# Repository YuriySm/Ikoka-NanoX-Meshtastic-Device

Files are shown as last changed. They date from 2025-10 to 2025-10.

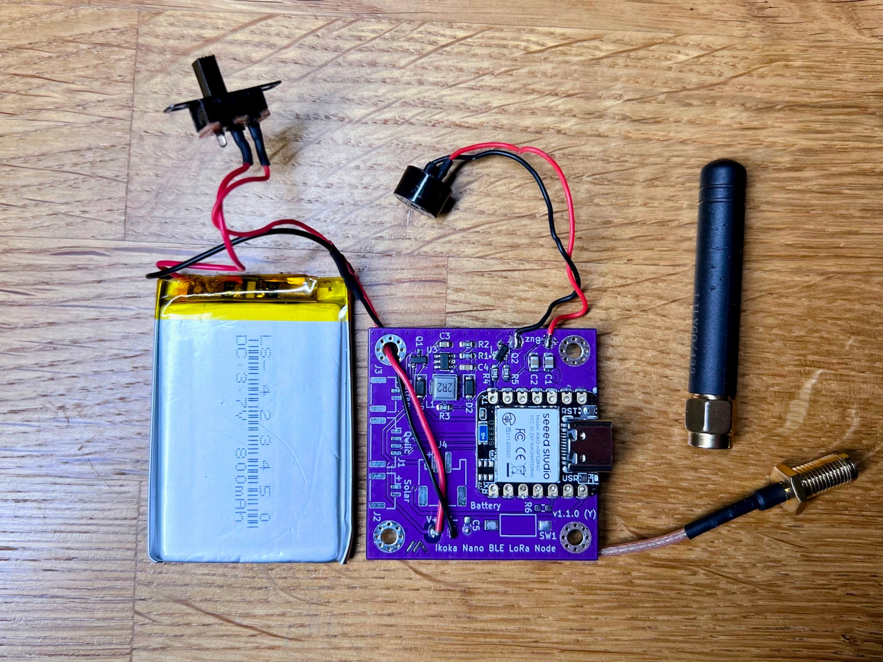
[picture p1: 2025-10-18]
media/1.1.1/Ikoka-NanoX-1.1.1-assembled.png

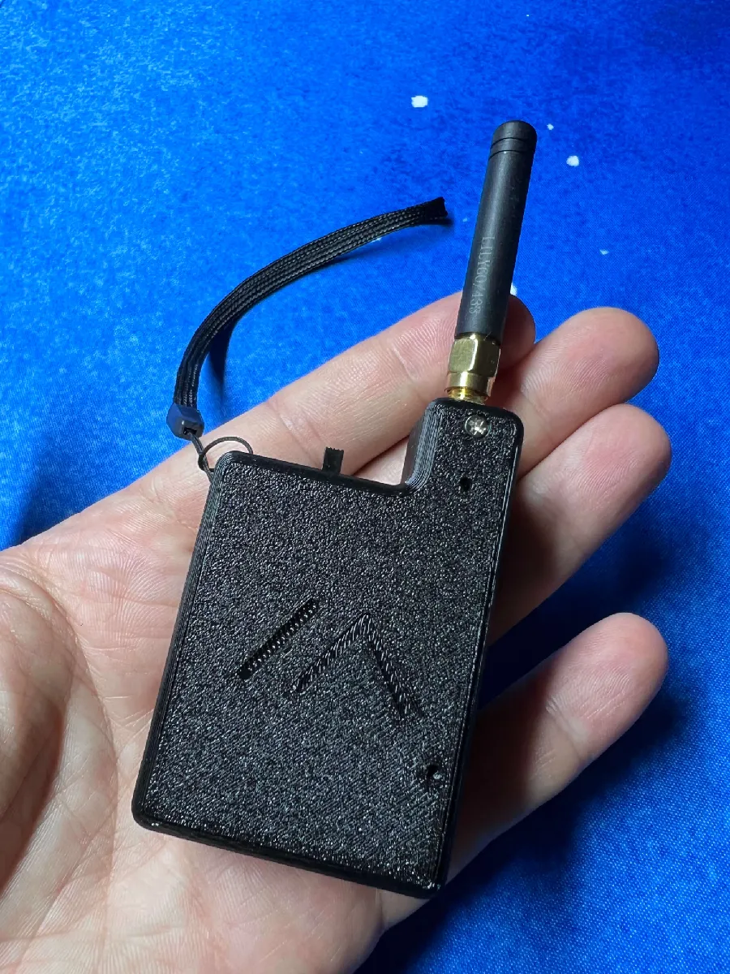
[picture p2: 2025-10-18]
media/1.1.1/Ikoka-NanoX-case.png

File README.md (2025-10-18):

Українська версія 🇺🇦 README доступна в [README_UK-UA.md](README_UK-UA.md).

Ikoka NanoX (eXtended) Meshtastic PCB is a fork of the [Ikoka Nano Meshtastic Device](https://github.com/ndoo/ikoka-nano-meshtastic-device) created by [Andrew Yong](https://ndoo.sg/projects:amateur_radio:meshtastic:diy_devices:ikoka_nano). This is a modified version of the original design released under CERN-OHL-P.

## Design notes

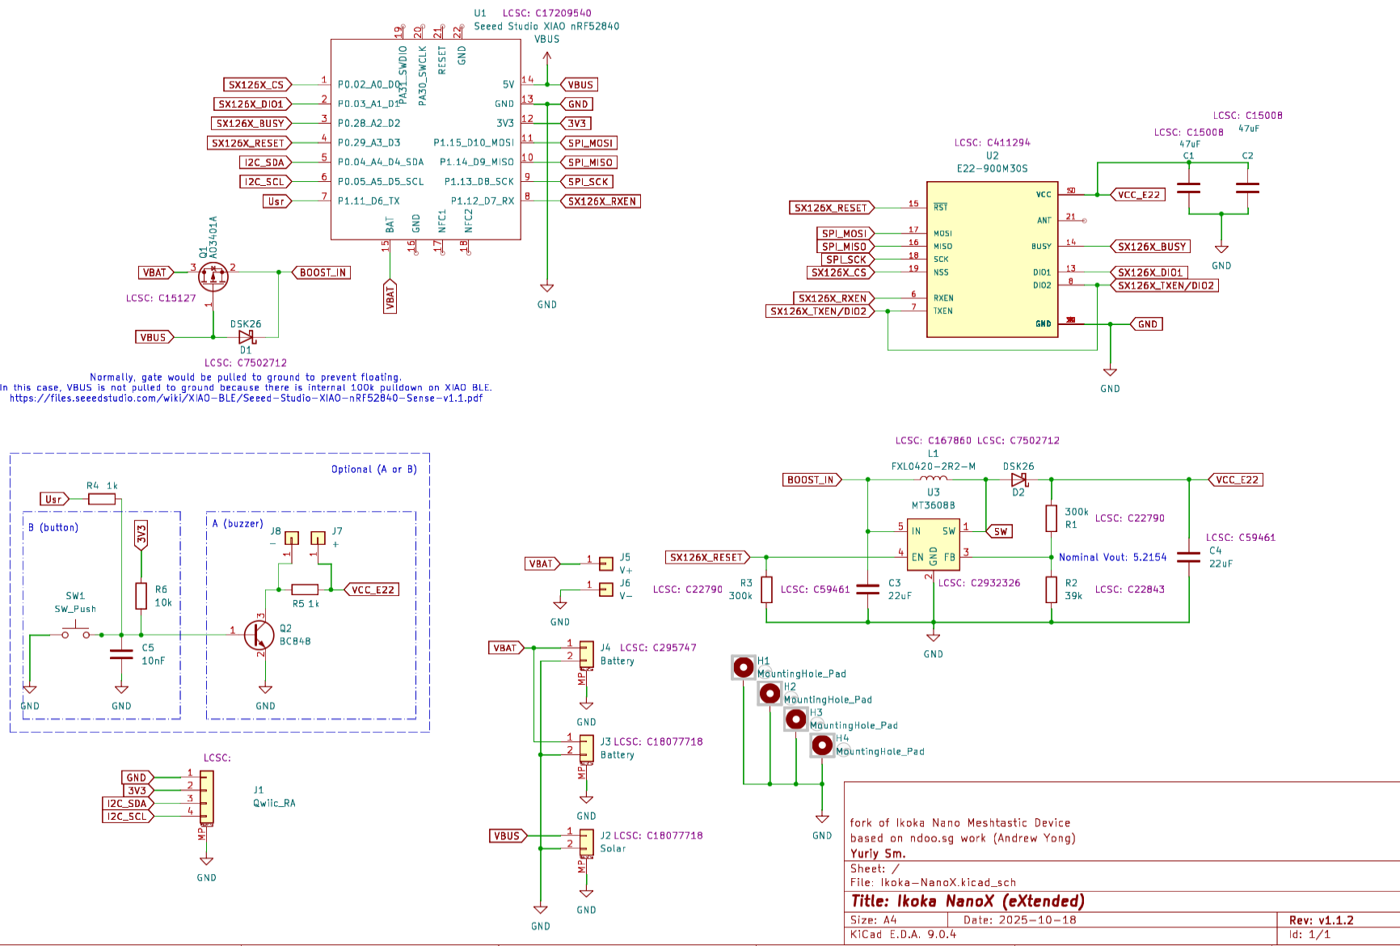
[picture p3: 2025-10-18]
media/1.1.2/IkokaNanoX-1.1.2-schematic.png

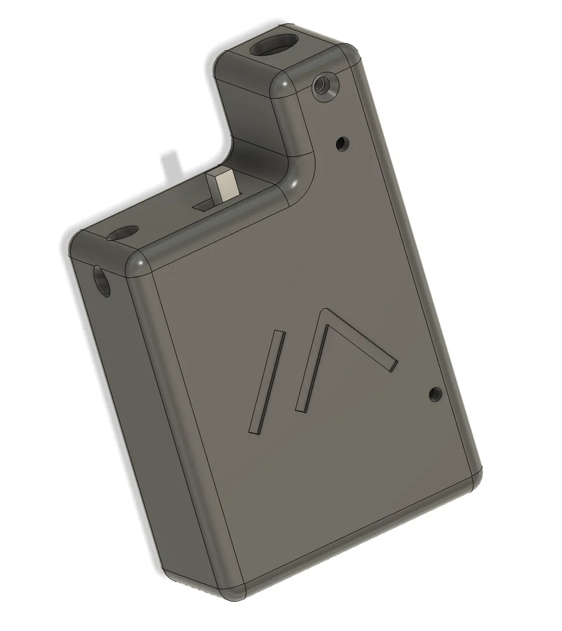
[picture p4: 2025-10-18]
media/1.1.1/Ikoka-NanoX-case-3D.png

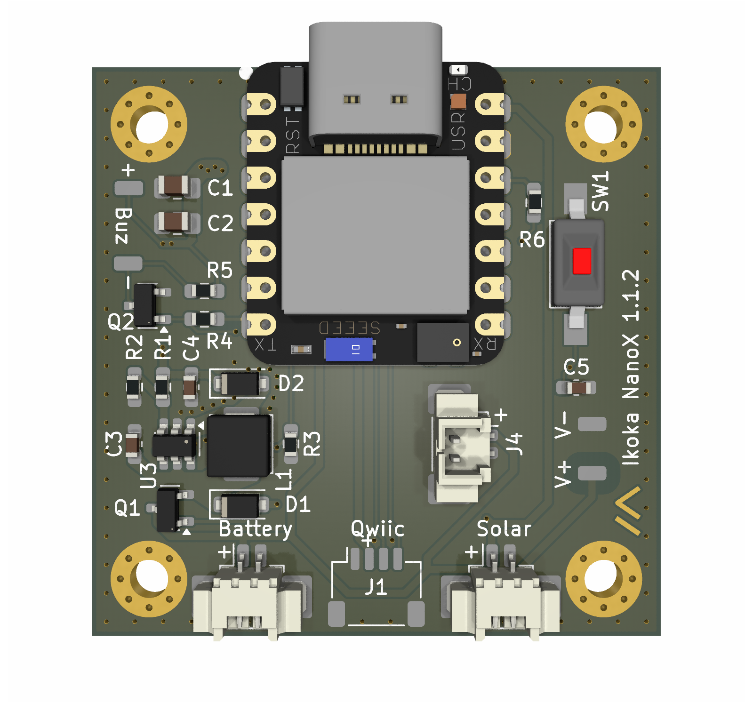
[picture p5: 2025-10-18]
media/1.1.2/Ikoka-NanoX-1.1.2-front.png

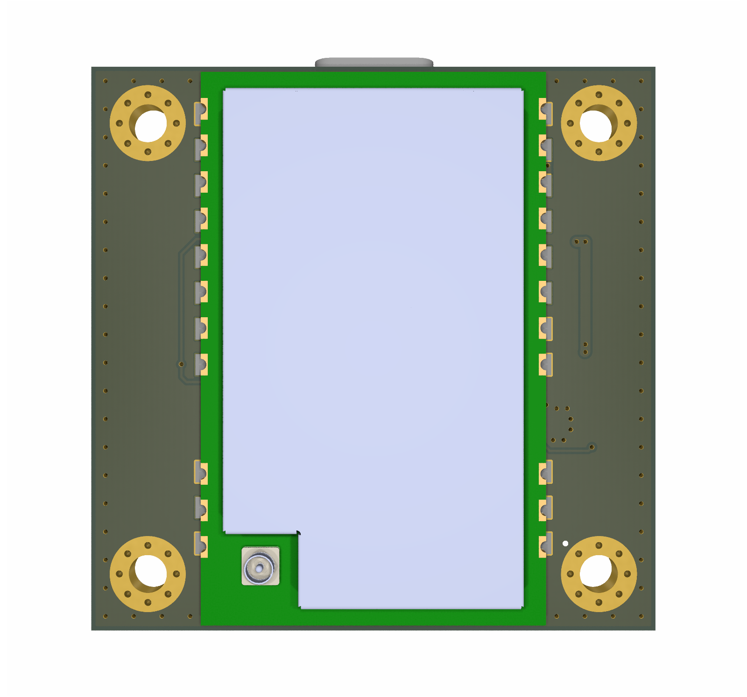
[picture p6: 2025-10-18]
media/1.1.2/Ikoka-NanoX-1.1.2-back.png

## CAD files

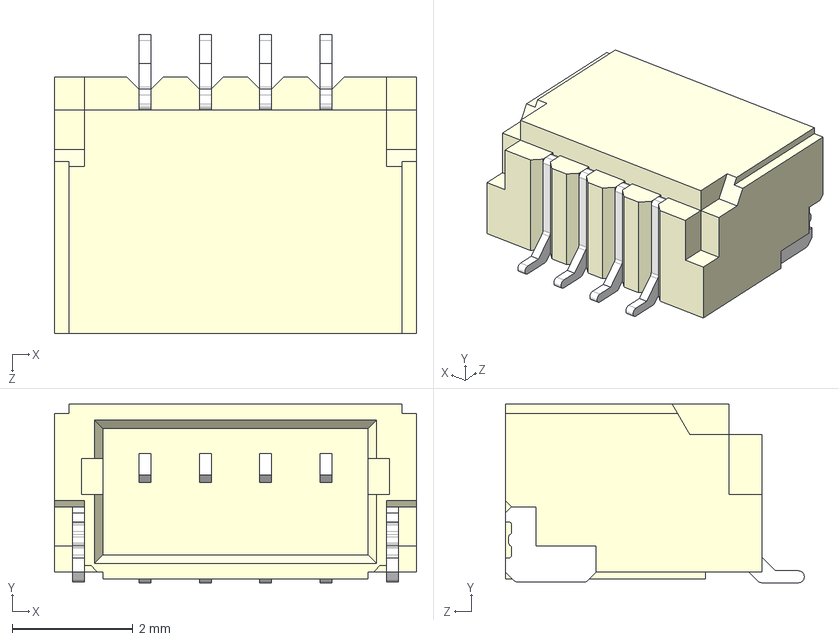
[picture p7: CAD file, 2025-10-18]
Ikoka-NanoX-KiCad/3dmodels/SM04B-SRSS-TB(LF)(SN)--3DModel-STEP-269445.STEP
6.00 x 2.96 x 4.95 mm

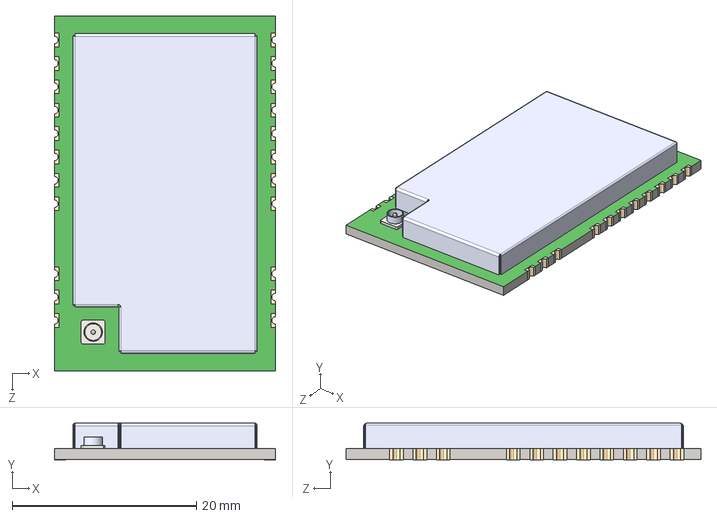
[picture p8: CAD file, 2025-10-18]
Ikoka-NanoX-KiCad/symbols/E22-900M30S/E22-900M30S.step
24.0 x 3.97 x 38.5 mm

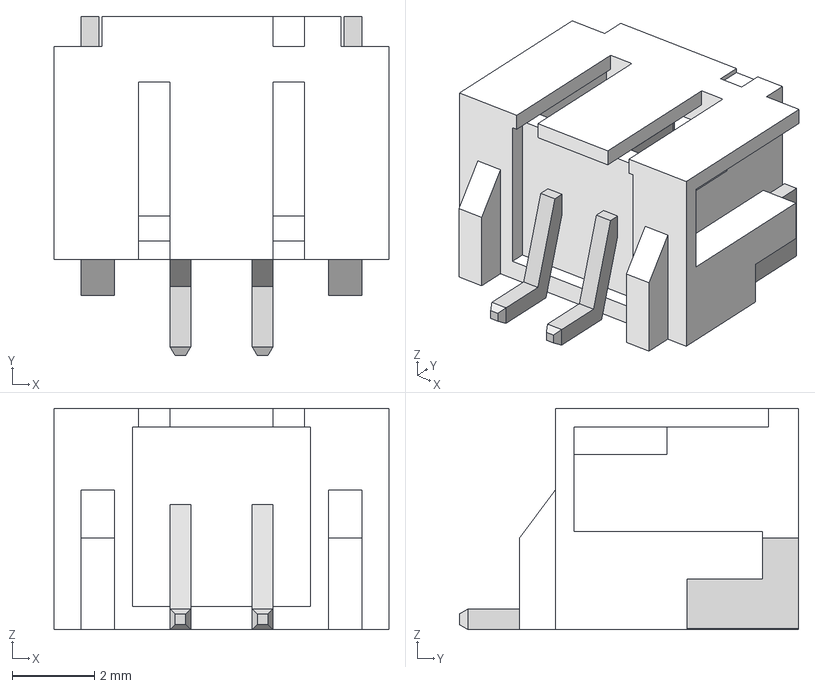
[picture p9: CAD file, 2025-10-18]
Ikoka-NanoX-KiCad/3dmodels/JST - PH - SMD (R) - 2Pin - 2.00mm.stp
8.15 x 8.26 x 5.38 mm

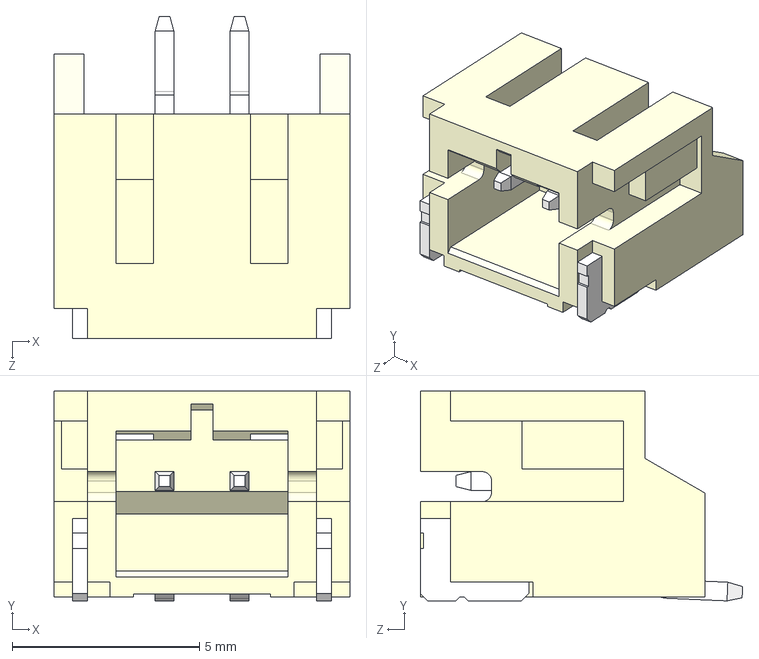
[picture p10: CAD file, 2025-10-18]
Ikoka-NanoX-KiCad/3dmodels/S2B-PH-SM4-TB--3DModel-STEP-269445.STEP
7.90 x 5.60 x 8.60 mm

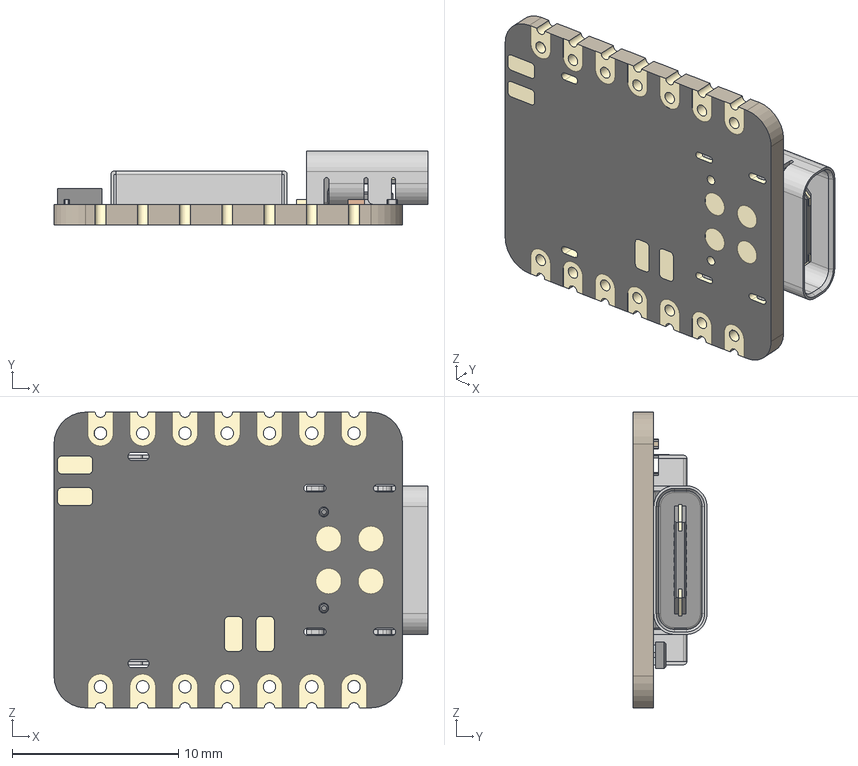
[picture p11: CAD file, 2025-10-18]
Ikoka-NanoX-KiCad/3dmodels/XIAO-nRF52840 v15.step
22.5 x 4.46 x 17.8 mm
BOSS-EXTRUDE14_8_
BOSS-EXTRUDE7_4_
BOSS-EXTRUDE7_3_
BOSS-EXTRUDE14_4_
BOSS-EXTRUDE14_2_
BOSS-EXTRUDE14_11_
BOSS-EXTRUDE7_7_
BOSS-EXTRUDE14_9_
BOSS-EXTRUDE14_3_
BOSS-EXTRUDE14_7_
MIRROR2
BOSS-EXTRUDE14_5_
BOSS-EXTRUDE14_12_
BOSS-EXTRUDE7_8_
BOSS-EXTRUDE7_1_
BOSS-EXTRUDE14_10_
BOSS-EXTRUDE7_9_
BOSS-EXTRUDE14_6_
BOSS-EXTRUDE14_1_
BOSS-EXTRUDE7_6_
BOSS-EXTRUDE7_2_
CUT-EXTRUDE5
BOSS-EXTRUDE7_5_
Shield
Pins
CAP x 2
ANT1
Silkscreen
CAP 3
LED
USR
2 v1

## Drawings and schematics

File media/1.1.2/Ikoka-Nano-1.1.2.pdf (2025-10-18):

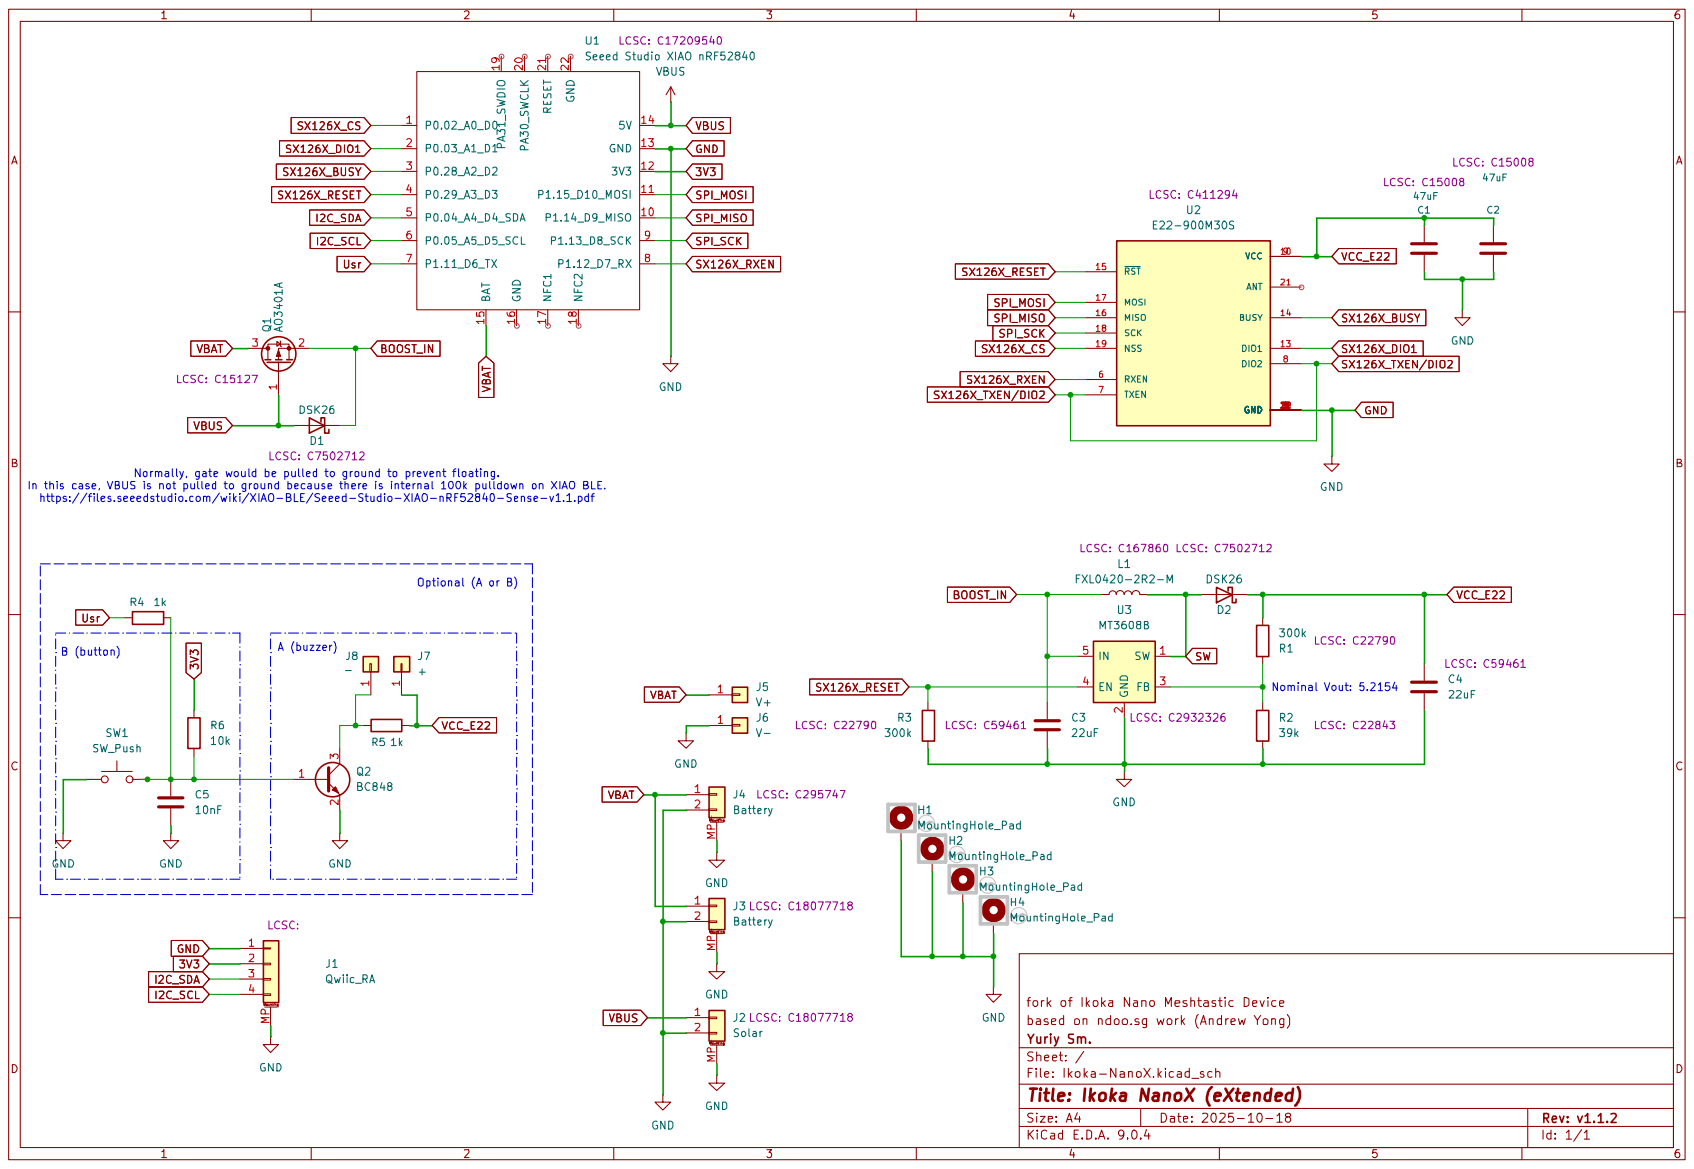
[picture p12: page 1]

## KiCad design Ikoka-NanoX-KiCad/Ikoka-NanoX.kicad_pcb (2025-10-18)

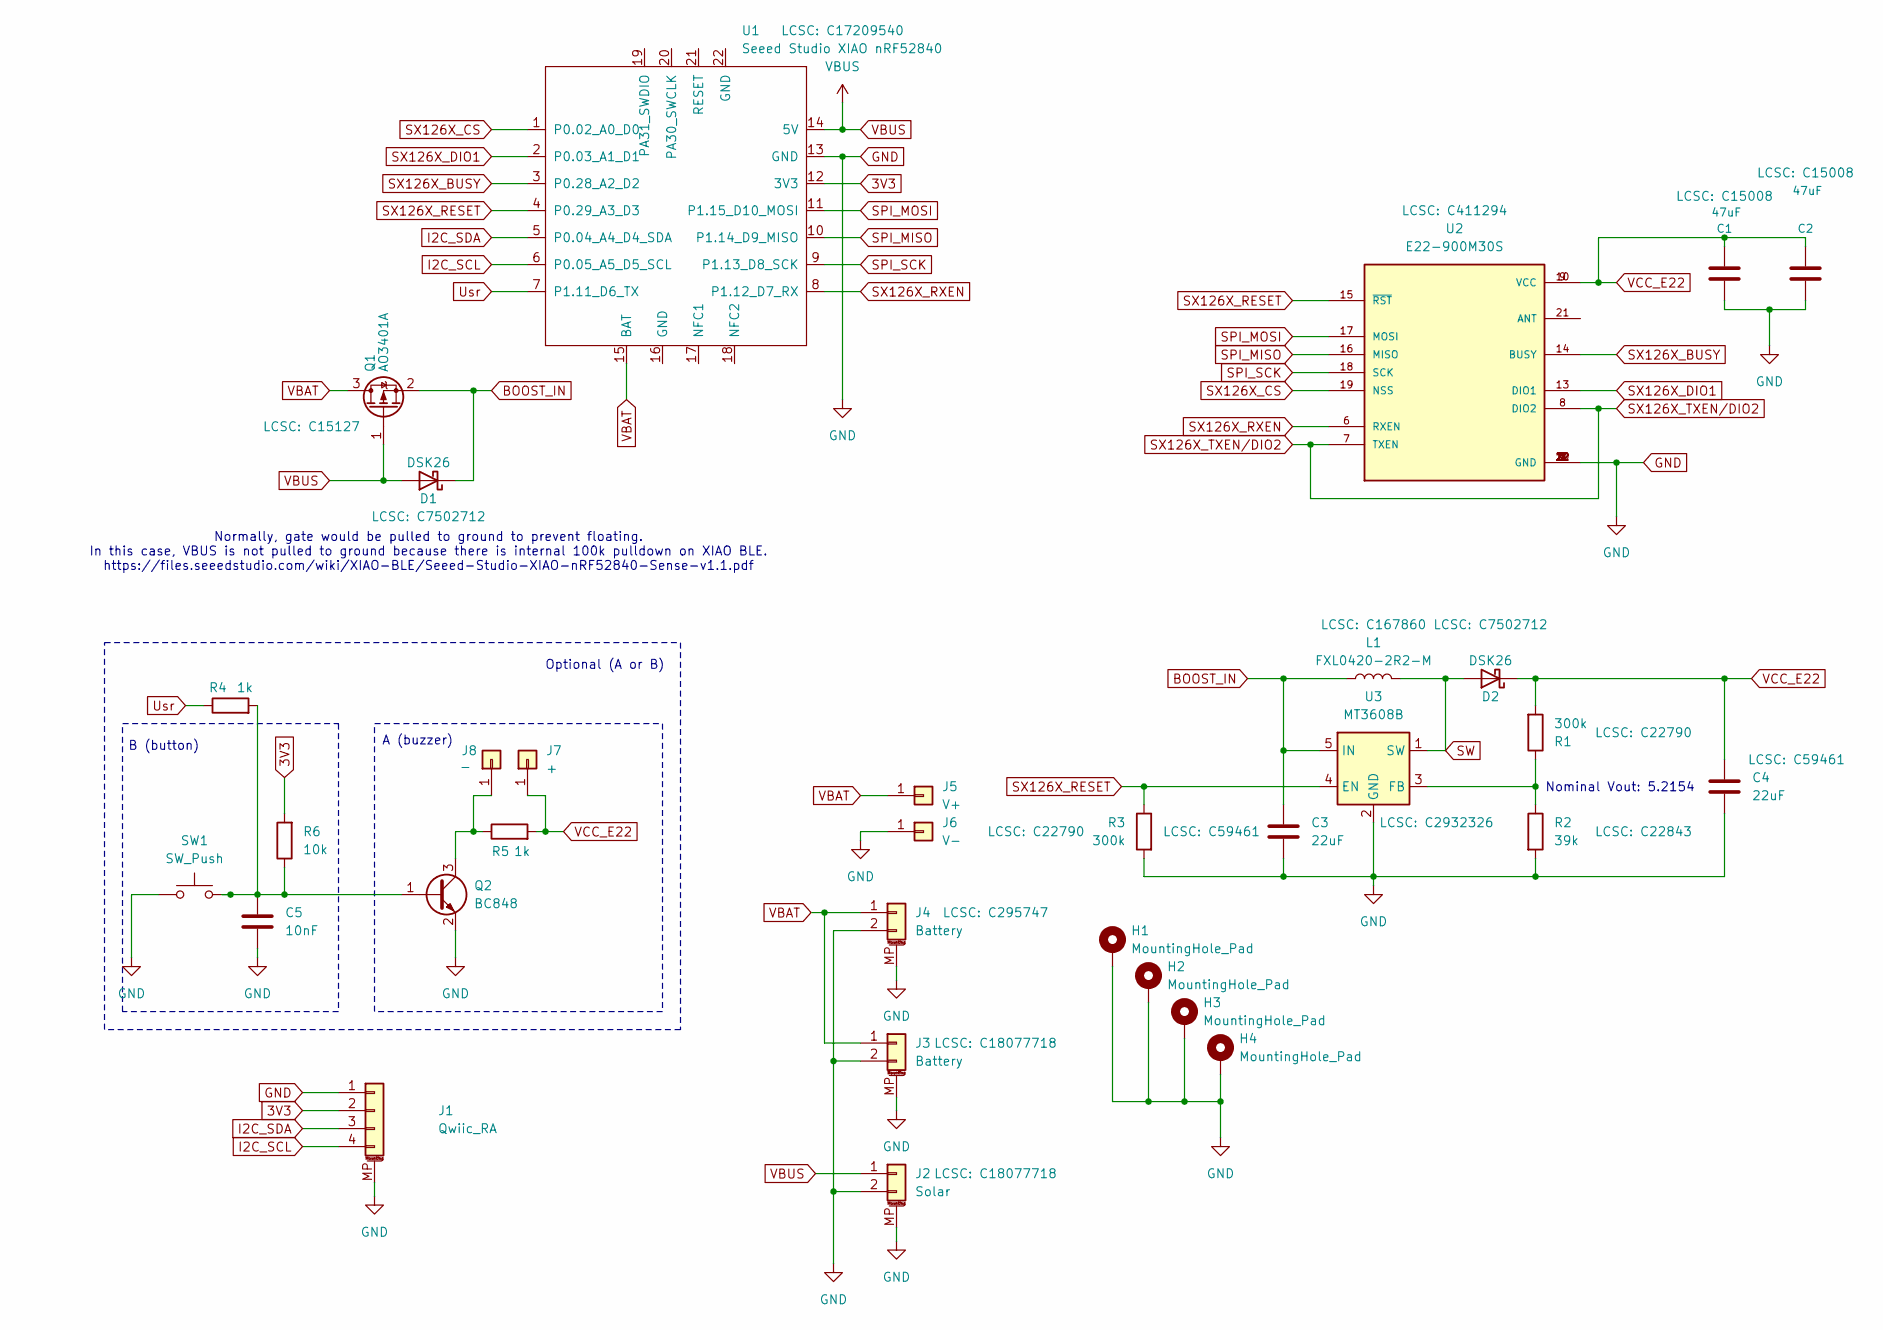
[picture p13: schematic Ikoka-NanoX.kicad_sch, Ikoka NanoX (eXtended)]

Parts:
C1, C2: 47uF; C_0805_2012Metric_Pad1.18x1.45mm_HandSolder; MPN CL31A107MQHNNNE; LCSC C15008
C3, C4: 22uF; C_0603_1608Metric_Pad1.08x0.95mm_HandSolder; MPN CL10A226MQ8NRNC; LCSC C59461
C5: 10nF; C_0603_1608Metric_Pad1.08x0.95mm_HandSolder; MPN CL10A226MQ8NRNC
D1, D2: DSK26; D_SOD-123F; LCSC C7502712
H1, H2, H3, H4: MountingHole_Pad; MountingHole_2.7mm_M2.5_Pad_Via
J1: Qwiic_RA; JST_SH_SM04B-SRSS-TB_1x04-1MP_P1.00mm_Horizontal
J2: Solar; Molex_PicoBlade_53261-0271_1x02-1MP_P1.25mm_Horizontal; LCSC C18077718
J3: Battery; Molex_PicoBlade_53261-0271_1x02-1MP_P1.25mm_Horizontal; LCSC C18077718
J4: Battery; Molex_PicoBlade_53398-0271_1x02-1MP_P1.25mm_Vertical; LCSC C295747
J5: V+; SolderWirePad_1x01_SMD_1x2mm
J6: V-; SolderWirePad_1x01_SMD_1x2mm
J7: +; SolderWirePad_1x01_SMD_1x2mm
J8: -; SolderWirePad_1x01_SMD_1x2mm
L1: FXL0420-2R2-M; L_Changjiang_FXL0420; MPN SMMS0650-220M; LCSC C167860
Q1: AO3401A; SOT-23; LCSC C15127
Q2: BC848; SOT-23
R1, R3: 300k; R_0603_1608Metric_Pad0.98x0.95mm_HandSolder; MPN 0603WAF1502T5E; LCSC C22790
R2: 39k; R_0603_1608Metric_Pad0.98x0.95mm_HandSolder; MPN 0603WAF1871T5E; LCSC C22843
R4, R5: 1k; R_0603_1608Metric_Pad0.98x0.95mm_HandSolder
R6: 10k; R_0603_1608Metric_Pad0.98x0.95mm_HandSolder
SW1: SW_Push; SW_SPST_FSMSM
U1: Seeed Studio XIAO nRF52840; XIAO-nRF52840-SMD_Handsoldering; LCSC C17209540
U2: E22-900M30S; XCVR_E22-900M30S; PARTREV 1.2; LCSC C411294
U3: MT3608B; SOT-23-6; LCSC C2932326

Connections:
3V3: J1.2, R6.2, U1.12 (3V3)
BOOST_IN: C3.1, D1.1 (K), L1.1, Q1.2 (S), U3.5 (IN)
GND: C1.1, C2.1, C3.2, C4.2, C5.2, H1.1, H2.1, H3.1, H4.1, J1.1, J1.MP (MountPin), J2.2, J2.MP (MountPin), J3.2, J3.MP (MountPin), J4.2, J4.MP (MountPin), J6.1, Q2.2 (E), R2.2, R3.2, SW1.1, U1.13 (GND), U2.1 (GND), U2.2 (GND), U2.3 (GND), U2.4 (GND), U2.5 (GND), U2.11 (GND), U2.12 (GND), U2.20 (GND), U2.22 (GND), U3.2 (GND)
I2C_SCL: J1.4, U1.6 (P0.05_A5_D5_SCL)
I2C_SDA: J1.3, U1.5 (P0.04_A4_D4_SDA)
unnamed: J8.1, Q2.3 (C), R5.1
unnamed: C5.1, Q2.1 (B), R4.2, R6.1, SW1.2
unnamed: R1.1, R2.1, U3.3 (FB)
SPI_MISO: U1.10 (P1.14_D9_MISO), U2.16 (MISO)
SPI_MOSI: U1.11 (P1.15_D10_MOSI), U2.17 (MOSI)
SPI_SCK: U1.9 (P1.13_D8_SCK), U2.18 (SCK)
SW: D2.2 (A), L1.2, U3.1 (SW)
SX126X_BUSY: U1.3 (P0.28_A2_D2), U2.14 (BUSY)
SX126X_CS: U1.1 (P0.02_A0_D0), U2.19 (NSS)
SX126X_DIO1: U1.2 (P0.03_A1_D1), U2.13 (DIO1)
SX126X_RESET: R3.1, U1.4 (P0.29_A3_D3), U2.15 (~RST), U3.4 (EN)
SX126X_RXEN: U1.8 (P1.12_D7_RX), U2.6 (RXEN)
SX126X_TXEN/DIO2: U2.7 (TXEN), U2.8 (DIO2)
Usr: R4.1, U1.7 (P1.11_D6_TX)
VBAT: J3.1, J4.1, J5.1, Q1.3 (D), U1.15 (BAT)
VBUS: D1.2 (A), J2.1, Q1.1 (G), U1.14 (5V)
VCC_E22: C1.2, C2.2, C4.1, D2.1 (K), J7.1, R1.2, R5.2, U2.9 (VCC), U2.10 (VCC)

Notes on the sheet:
A (buzzer)
Nominal Vout: 5.2154
B (button)
Normally, gate would be pulled to ground to prevent floating. In this case, VBUS is not pulled to ground because there is internal 100k pulldown on XIAO BLE. https://files.seeedstudio.com/wiki/XIAO-BLE/Seeed-Studio-XIAO-nRF52840-Sense-v1.1.pdf
Optional (A or B)

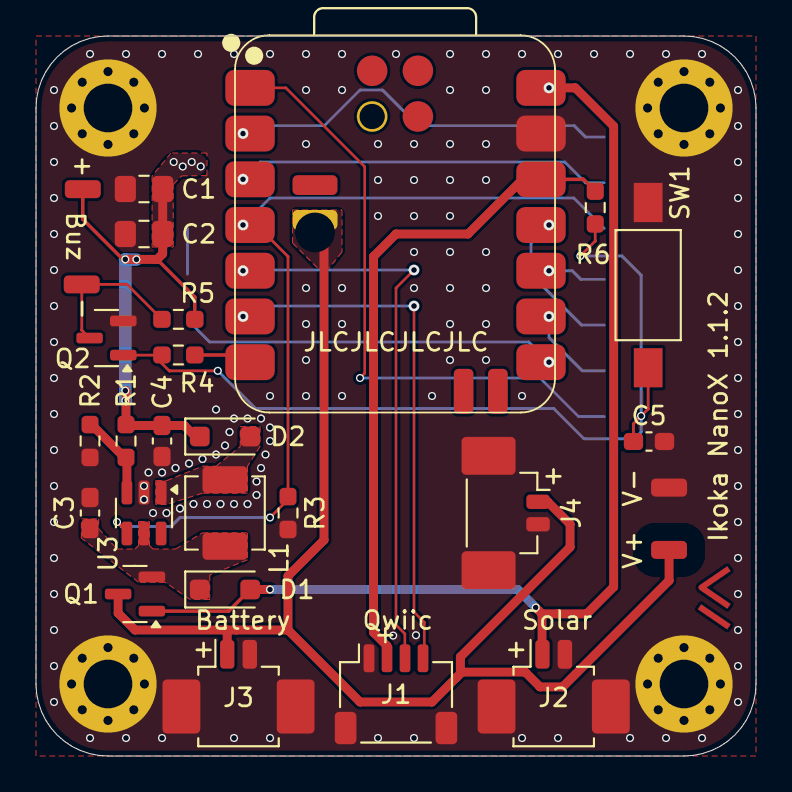
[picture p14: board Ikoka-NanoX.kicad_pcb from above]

Board: 2 copper layers, 40.0 x 40.0 mm, 33 parts (1 on the bottom side), 22 nets.

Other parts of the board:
SYM1: Meshtastic Logo; meshtastic_logo

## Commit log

2025-10-11 Fork from original ikoka Nano by Andrew Yong. PCB and schematic additions.
2025-10-18 README updated, KiCad improvements
    [E22-900M30S--3DModel-STEP-418109.STEP, E22-900M30S.step, Ikoka-NanoX.kicad_pcb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]
